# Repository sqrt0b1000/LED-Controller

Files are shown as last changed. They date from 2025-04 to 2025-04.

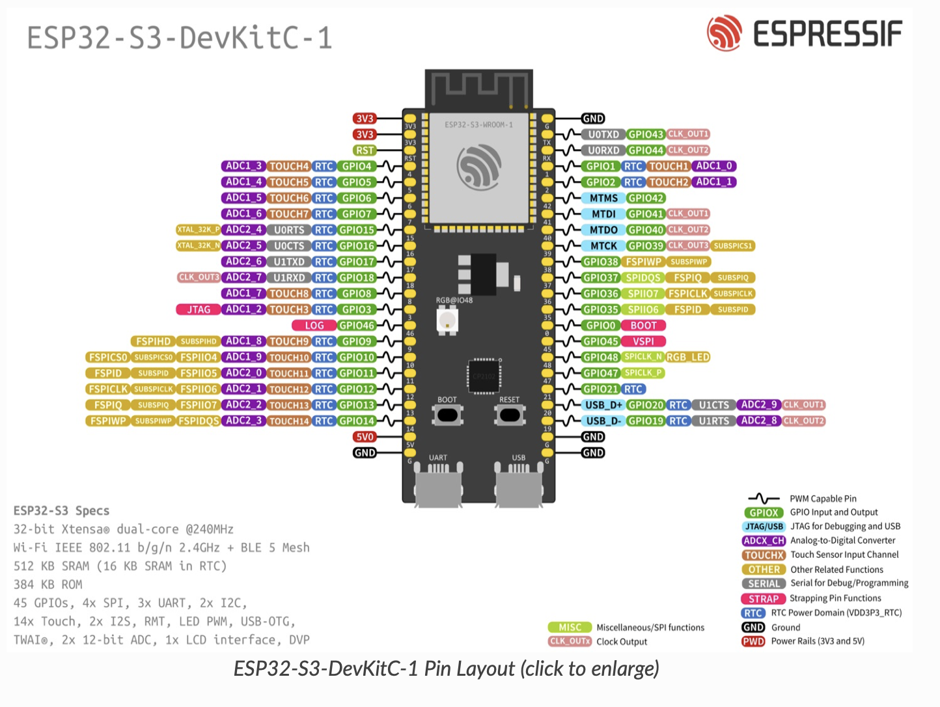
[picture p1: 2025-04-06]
Datasheets/ESP32-S3/Ports-ESP_S3_DevKitC_1.png

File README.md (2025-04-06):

# LED Controller: Schaltplatine für WLED

## Disclaimer

Using this software and hardware is the users responsibility as it is not bug free.
Therefore contributors of this repo are not reliable for anything
including but not limited to spontaneous combustion of the entire led strip, the house and the inevitable heat death of the universe.

Also see: [LICENSE](./LICENSE)

## Features

- 3 PWM Ausgänge zum Steuern von 12 V RGB Kanälen
- Steuerung durch WIFI (einwahl in WLAN möglich oder Erstellen eines eigenen Accesspoints)
- 6 weitere GPIO Pins, z.B. für weitere Buttons,…
- RX/TX Verbindungen (Flashen des ESP32)

## Zusätzliche Features

- 8 PWM Ausgänge als Datenleitungen für individuell addressierbare LEDs
  - Signal auf 5 V
  - Mögliche LED - Strips (nicht vollständig)
    - WS2812
    - WS2805

## Pins

| ESP Pin Name | Board Output | Usage |
| ---:| ---:| ---:|
| TXD0 | J  7 | GPIO1, U0TXD, CLK_OUT3, EMAC_RXD2 |
| RXD0 | J  8 | GPIO3, U0RXD, CLK_OUT2 |
| IO 18 | LED-Out | MOSFET Transisotr 12 V |
| IO 19 | LED-Out | MOSFET Transisotr 12 V |
| IO 21 | LED-Out | MOSFET Transisotr 12 V |
| IO  2 | J  5 | MOSFET Transistor  5 V |
| IO 15 | J 11 | MOSFET Transistor  5 V |
| IO 13 | J 12 | MOSFET Transistor  5 V |
| IO 12 | J 13 | MOSFET Transistor  5 V |
| IO 14 | J 14 | MOSFET Transistor  5 V |
| IO 27 | J 15 | MOSFET Transistor  5 V |
| IO 26 | J 16 | MOSFET Transistor  5 V |
| IO 25 | J 17 | MOSFET Transistor  5 V |
| SENSOR_VN | J 4 | GPIO39, ADC1_CH3, RTC_GPIO3 |
| SENSOR_VP | J 5 | GPIO36, ADC1_CH0, RTC_GPIO0 |
| - | J  9 | Ground |
|  - | J 10 | Power 3.3 V |
|  - | J  2| Power  12 V |

Für mehr Details siehe das Datasheet des Controllers: [Datasheet](./Datasheets/ESP32/esp32-wroom-32_datasheet_en.pdf))

## Probleme mit v01

- sehr hohe Last auf Ground
  - diese Leiterbahnen sollten breiter und idealerweise kürzer sein
- zentraler Ground von ESP32 nicht wirklich lötbar
  - hier richtige Löcher, damit man auf der Rückseite mit dem Lötkolben auch hinkommt
- Pads von Spanungsregulierer anpassen
  - verhindern von Verbindungen von 12 V und 3.3 V beim Löten
- anpassen der Löchergrößen um Pins einfacher durchsteckbar zu machen
- fehlender Pin für 5 V
- Verbindung von Dir mit 5 V, damit Richtung stimmt
- mehr Pins für GND and 12 V
- weitere Pins für freie IO Ports
- Benennung und Beschriftung der Pins
- verbinde benutzbare Pins, nicht (nicht 17-22, da diese intern vom ESP32 benutzt werden, und nicht verbunden sind)

## Flashen des ESP32

(Nur für einen neuen Controller notwendig, alle weiteren Updates können OTA erfolgen)

Verbinden von RX/TX mit Flipper, oder anderem Board.
Flipper oder alternatives Board als UART-USB-Bridge verwenden.
In WLED folgenden Command ausführen.
Davor den Boot-Button am Controller drücken,
um diesen in den Boot-Modus zu versetzen.

´´´bash
pio run -e esp32dev -t upload
´´´
Nach erfolgreichem Flashen den ESP32 mit dem Reset-Button resetten.

## Links

### WLED

- [WLED-Knowlege base](https://kno.wled.ge)
- [WLED-Github](https://github.com/WLED/WLED)
- [WLED-MM](https://github.com/MoonModules/WLED-MM): More advanced WLED with additional / experimental features

### LED-FX (Audio-Reactive)

- [LED-FX-Github](https://github.com/LedFx/LedFx)
- [LED-FX-Documentation](https://docs.ledfx.app/en/latest/installing.html)

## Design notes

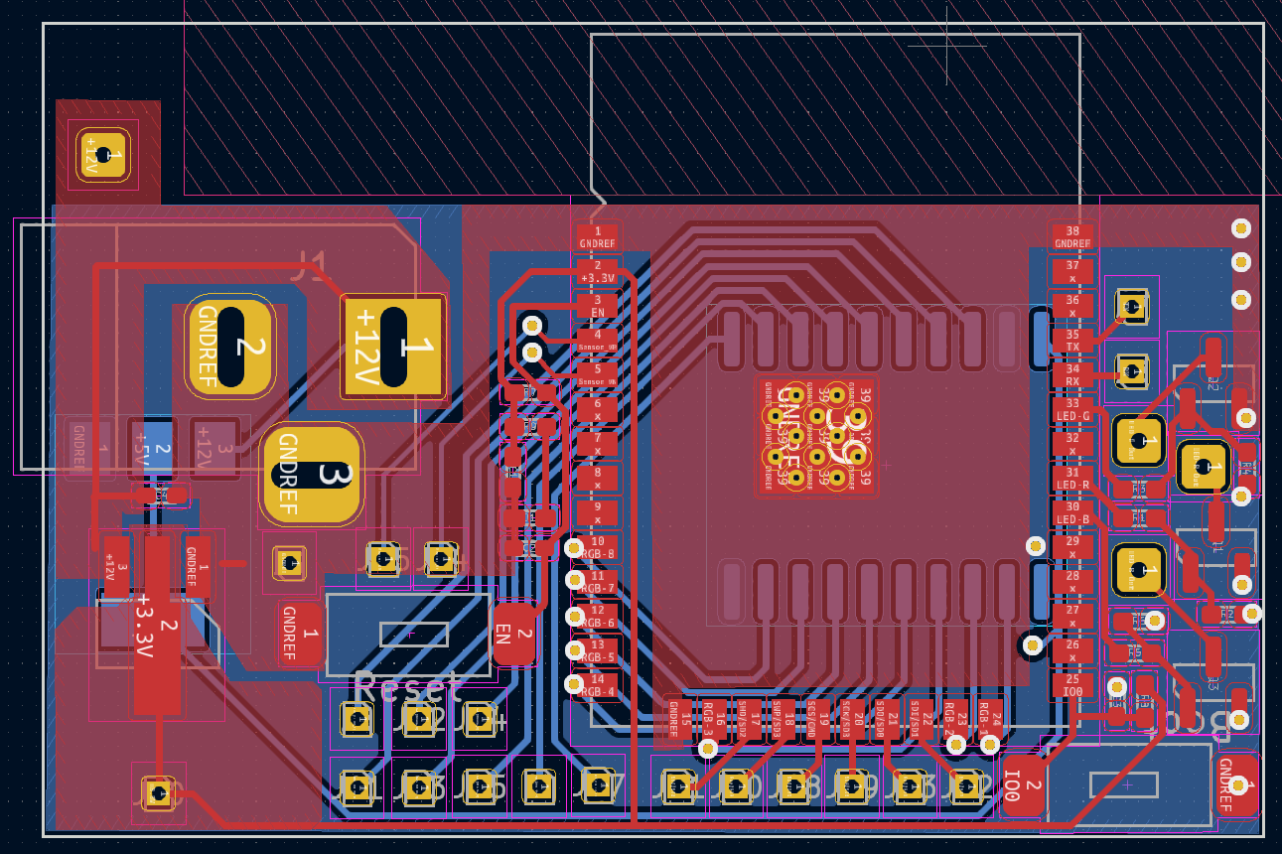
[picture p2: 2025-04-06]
Exports/PCP-Pins.png

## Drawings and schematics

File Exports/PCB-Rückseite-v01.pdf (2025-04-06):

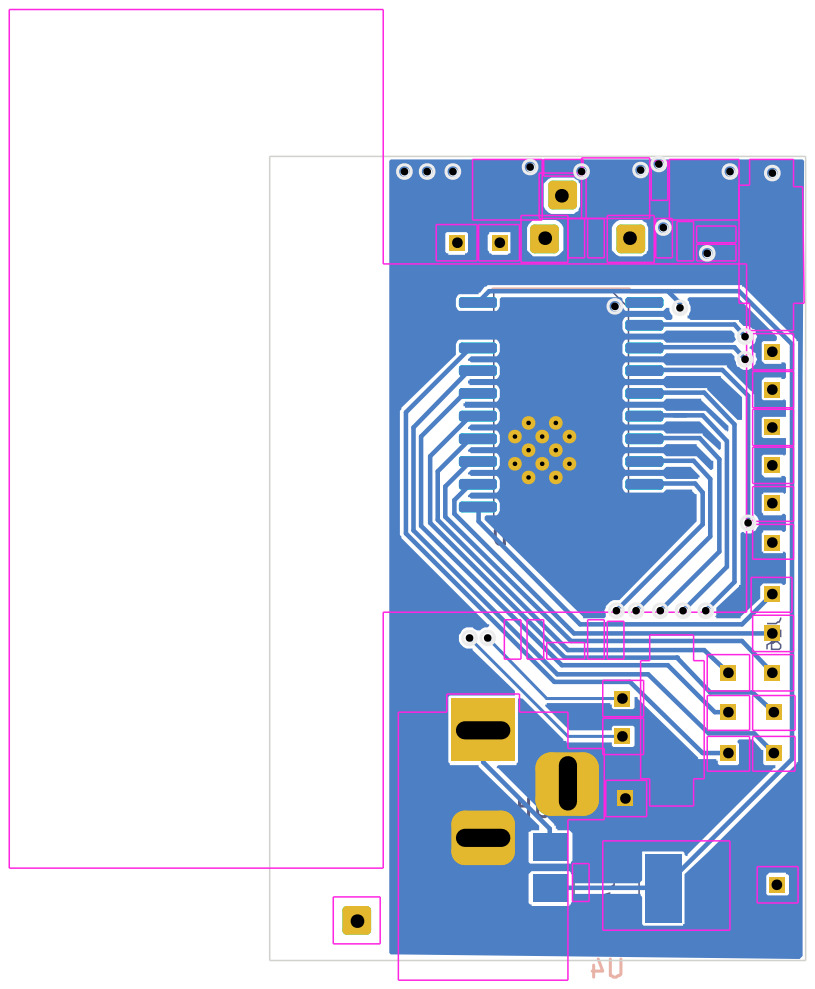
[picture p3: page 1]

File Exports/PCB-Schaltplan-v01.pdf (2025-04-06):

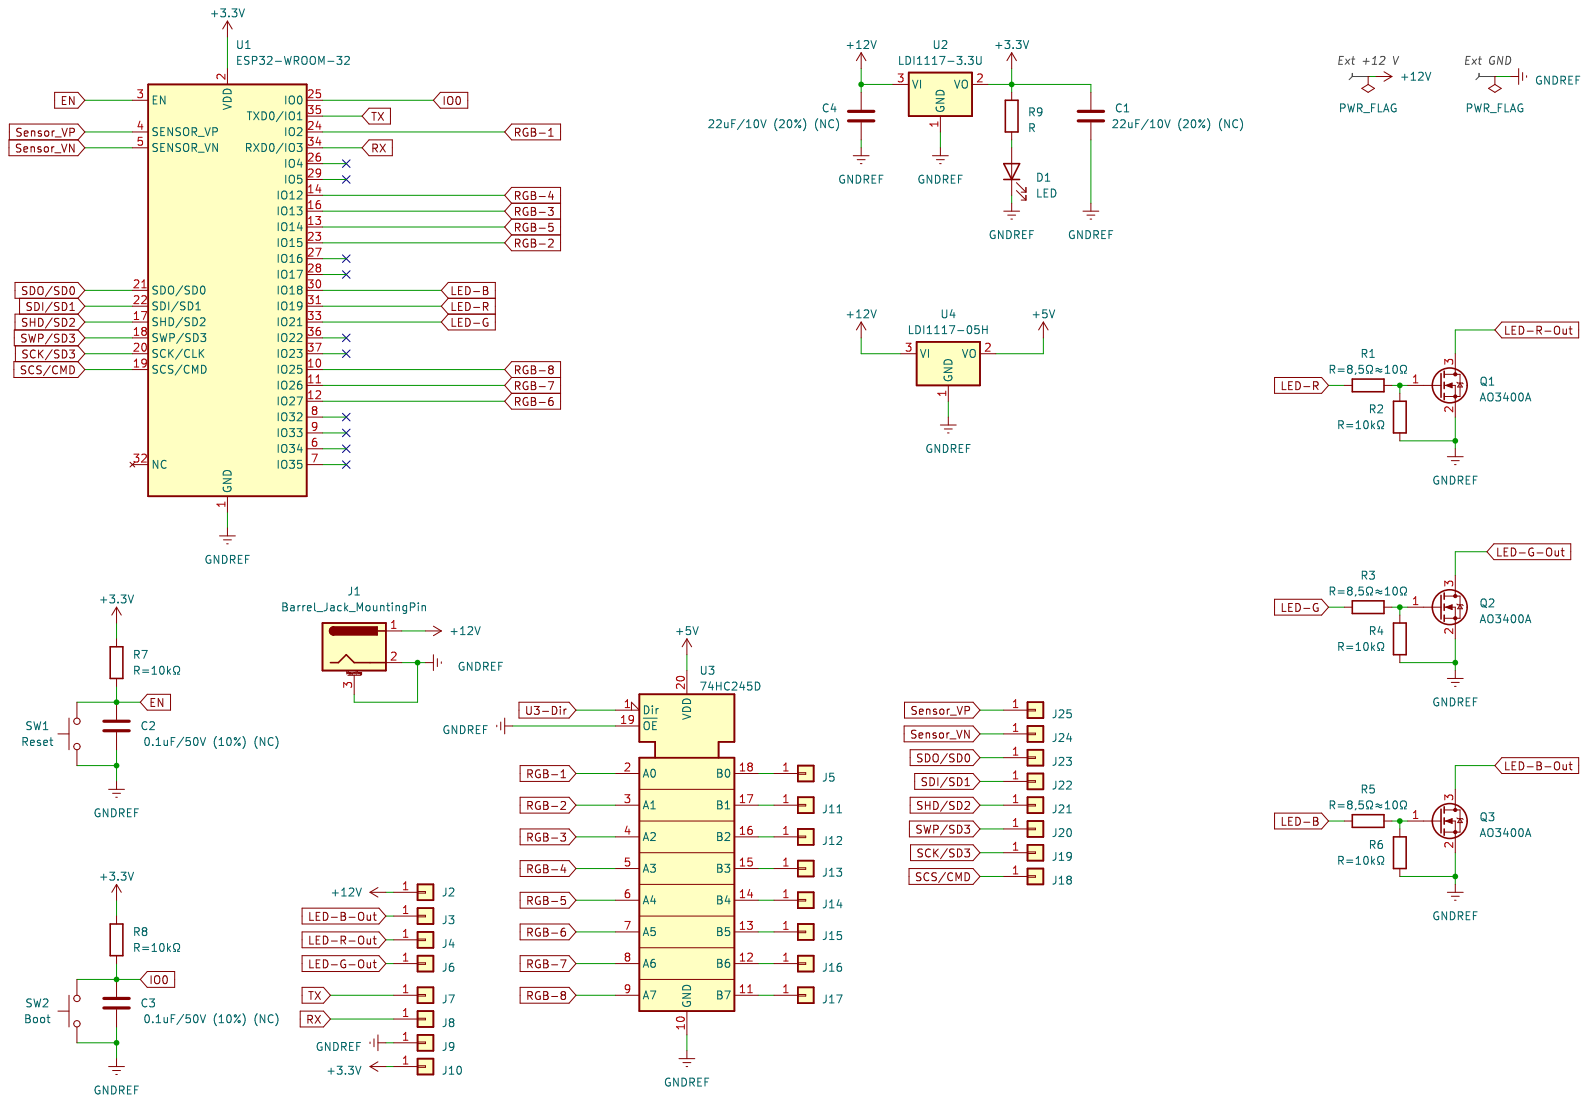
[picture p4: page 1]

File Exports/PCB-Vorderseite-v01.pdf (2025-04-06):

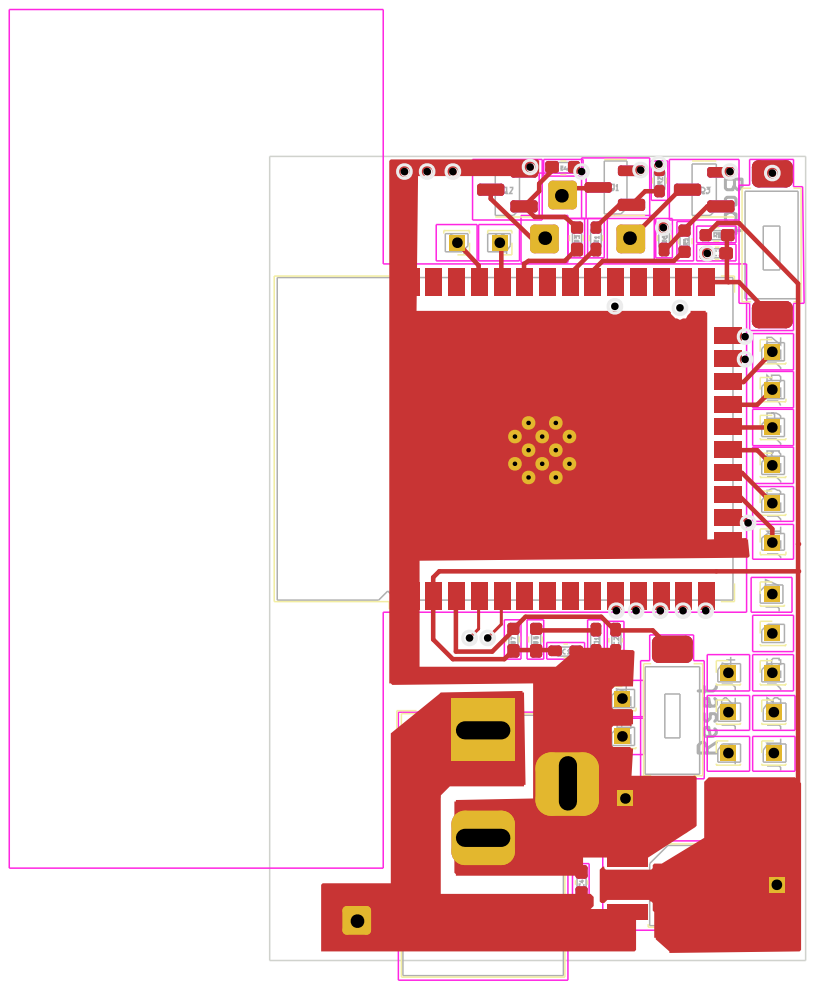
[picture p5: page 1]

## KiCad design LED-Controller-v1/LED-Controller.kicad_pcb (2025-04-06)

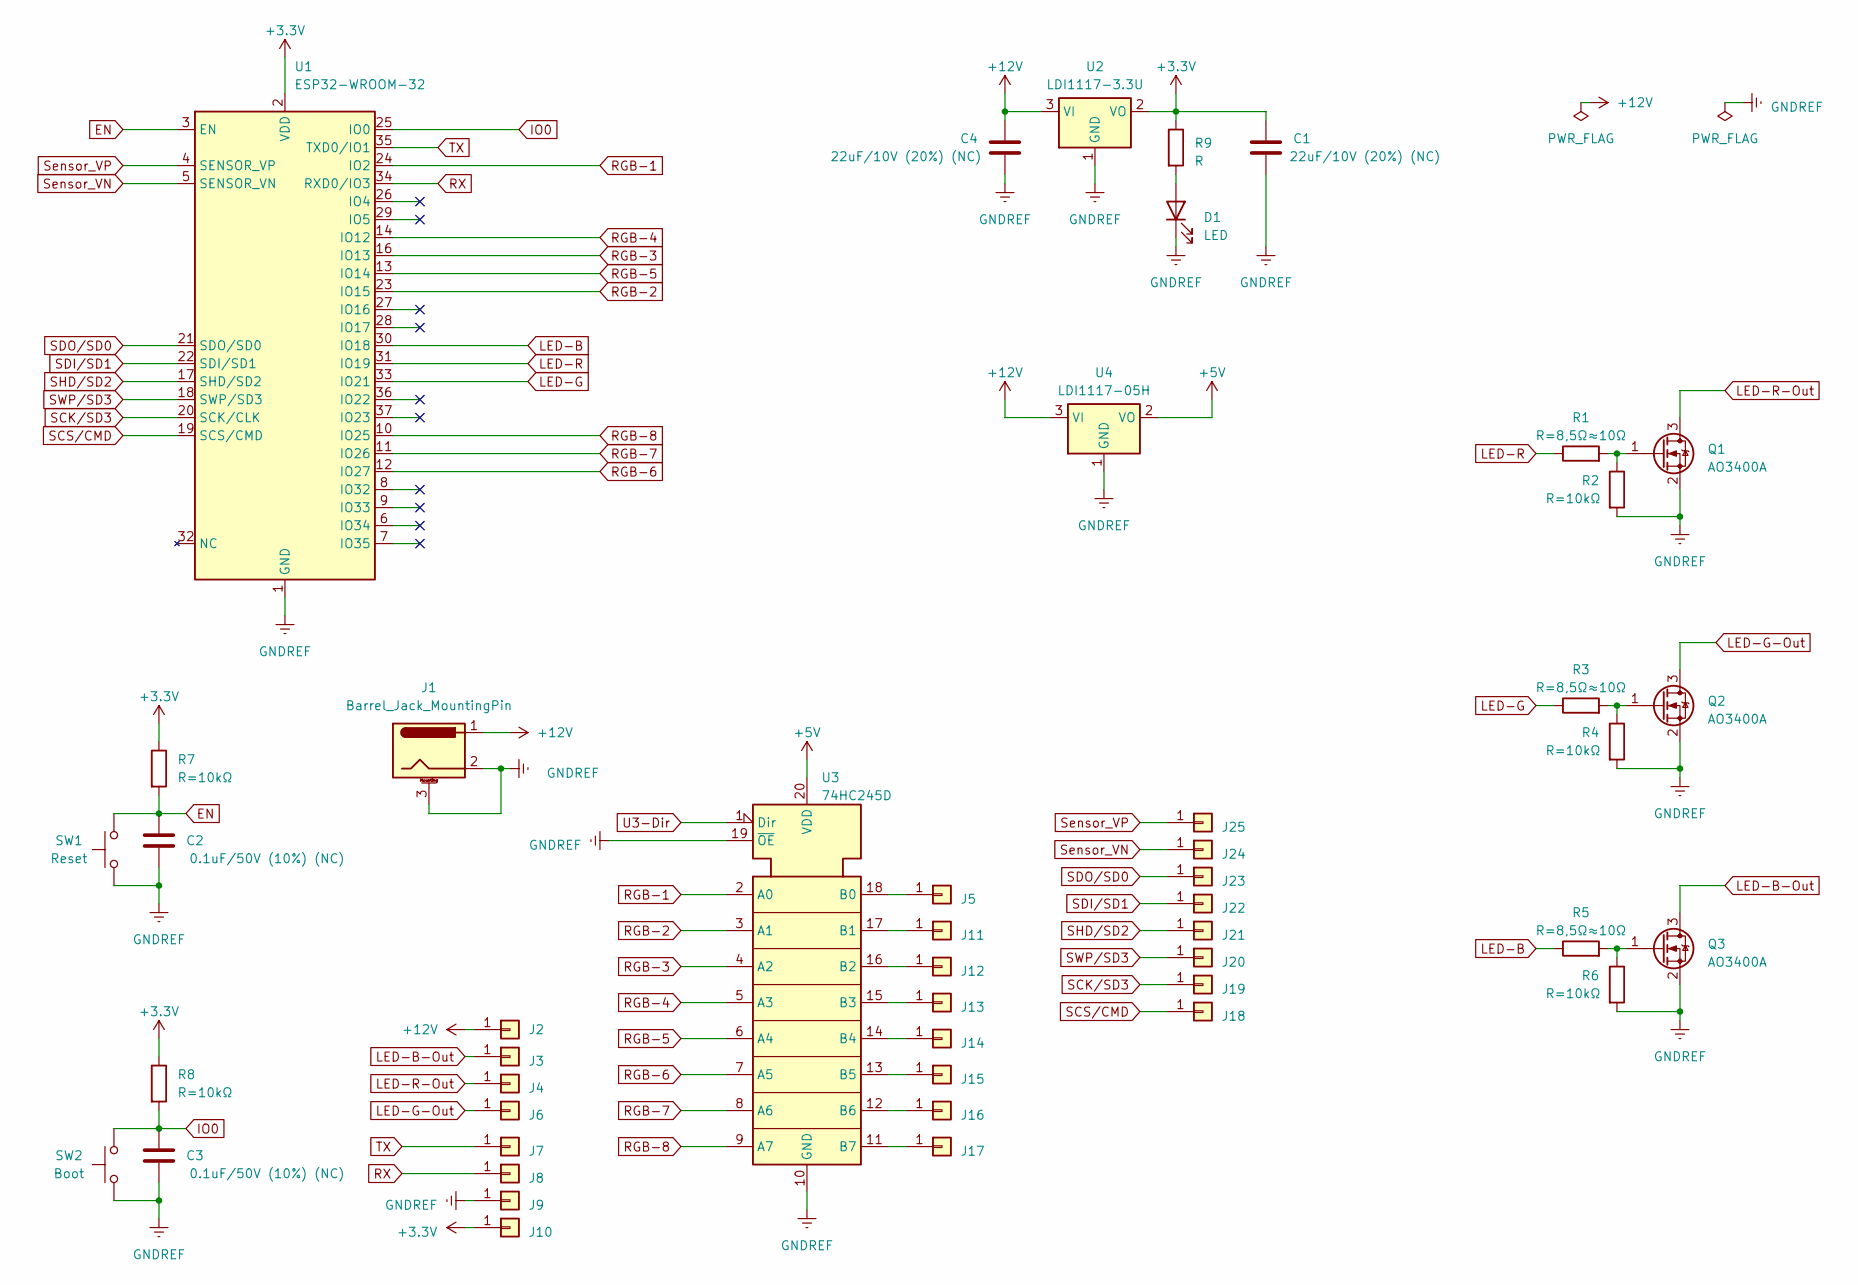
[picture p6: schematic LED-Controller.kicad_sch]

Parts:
C1, C4: 22uF/10V (20%) (NC); C_0402_1005Metric_Pad0.74x0.62mm_HandSolder
C2, C3: 0.1uF/50V (10%) (NC); C_0402_1005Metric_Pad0.74x0.62mm_HandSolder
D1: LED; D_0402_1005Metric_Pad0.77x0.64mm_HandSolder
J1: Barrel_Jack_MountingPin; BarrelJack_Horizontal
J2, J3, J4, J6: Conn_01x01; SolderWire-0.1sqmm_1x01_D0.4mm_OD1mm
J5, J7, J8, J9, J10, J11, J12, J13, J14, J15, J16, J17, J18, J19, J20, J21, J22, J23, J24, J25: Conn_01x01; PinHeader_1x01_P1.00mm_Vertical
Q1, Q2, Q3: AO3400A; SOT-23
R1, R3, R5: R=8,5Ω≈10Ω; R_0402_1005Metric_Pad0.72x0.64mm_HandSolder
R2, R4, R6, R7, R8: R=10kΩ; R_0402_1005Metric_Pad0.72x0.64mm_HandSolder
R9: R; R_0402_1005Metric_Pad0.72x0.64mm_HandSolder
SW1: Reset; TACTM-34N-F
SW2: Boot; TACTM-34N-F
U1: ESP32-WROOM-32
U2: LDI1117-3.3U; SOT-89-3_Handsoldering
U3: 74HC245D; SOIC-20W_7.5x12.8mm_P1.27mm
U4: LDI1117-05H; SOT-223-3_TabPin2

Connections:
+3.3V: C1.2, J10.1, R7.1, R8.1, R9.1, U1.2 (VDD), U2.2 (VO)
+5V: U3.20 (VDD), U4.2 (VO)
+12V: C4.2, J1.1, J2.1, U2.3 (VI), U4.3 (VI)
EN: C2.2, R7.2, SW1.2, U1.3 (EN)
GNDREF: C1.1, C2.1, C3.1, C4.1, D1.1 (K), J1.2, J1.3 (MountPin), J9.1, Q1.2 (S), Q2.2 (S), Q3.2 (S), R2.2, R4.2, R6.2, SW1.1, SW2.1, U1.1 (GND), U1.15 (GND), U1.38 (GND), U1.39 (GND), U2.1 (GND), U3.10 (GND), U3.19 (~OE), U4.1 (GND)
IO0: C3.2, R8.2, SW2.2, U1.25 (IO0)
LED-B: R5.1, U1.30 (IO18)
LED-B-Out: J3.1, Q3.3 (D)
LED-G: R3.1, U1.33 (IO21)
LED-G-Out: J6.1, Q2.3 (D)
LED-R: R1.1, U1.31 (IO19)
LED-R-Out: J4.1, Q1.3 (D)
unnamed: D1.2 (A), R9.2
unnamed: J5.1, U3.18 (B0)
unnamed: J11.1, U3.17 (B1)
unnamed: J12.1, U3.16 (B2)
unnamed: J13.1, U3.15 (B3)
unnamed: J14.1, U3.14 (B4)
unnamed: J15.1, U3.13 (B5)
unnamed: J16.1, U3.12 (B6)
unnamed: J17.1, U3.11 (B7)
unnamed: Q1.1 (G), R1.2, R2.1
unnamed: Q2.1 (G), R3.2, R4.1
unnamed: Q3.1 (G), R5.2, R6.1
RGB-1: U1.24 (IO2), U3.2 (A0)
RGB-2: U1.23 (IO15), U3.3 (A1)
RGB-3: U1.16 (IO13), U3.4 (A2)
RGB-4: U1.14 (IO12), U3.5 (A3)
RGB-5: U1.13 (IO14), U3.6 (A4)
RGB-6: U1.12 (IO27), U3.7 (A5)
RGB-7: U1.11 (IO26), U3.8 (A6)
RGB-8: U1.10 (IO25), U3.9 (A7)
RX: J8.1, U1.34 (RXD0/IO3)
SCK/SD3: J19.1, U1.20 (SCK/CLK)
SCS/CMD: J18.1, U1.19 (SCS/CMD)
SDI/SD1: J22.1, U1.22 (SDI/SD1)
SDO/SD0: J23.1, U1.21 (SDO/SD0)
SHD/SD2: J21.1, U1.17 (SHD/SD2)
SWP/SD3: J20.1, U1.18 (SWP/SD3)
Sensor_VN: J24.1, U1.5 (SENSOR_VN)
Sensor_VP: J25.1, U1.4 (SENSOR_VP)
TX: J7.1, U1.35 (TXD0/IO1)
U3-Dir: U3.1 (Dir)

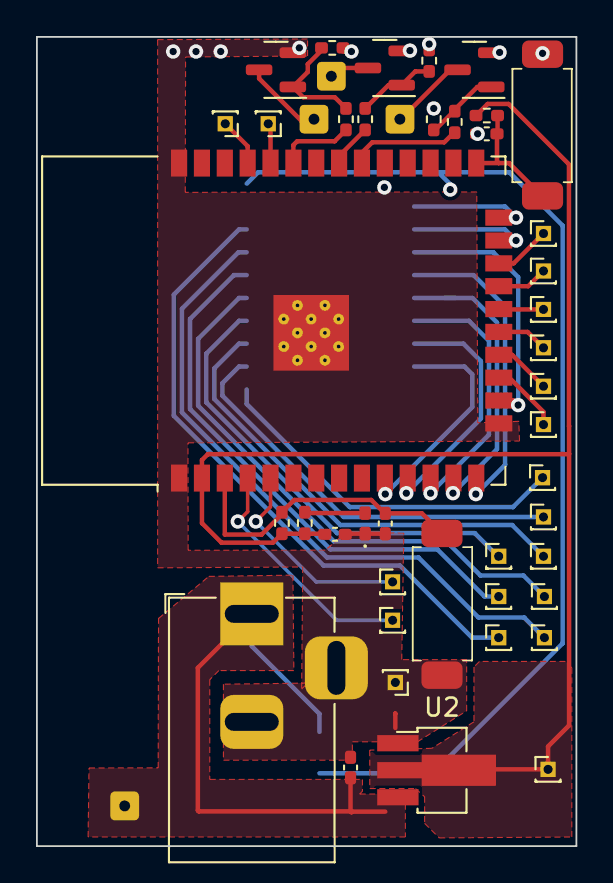
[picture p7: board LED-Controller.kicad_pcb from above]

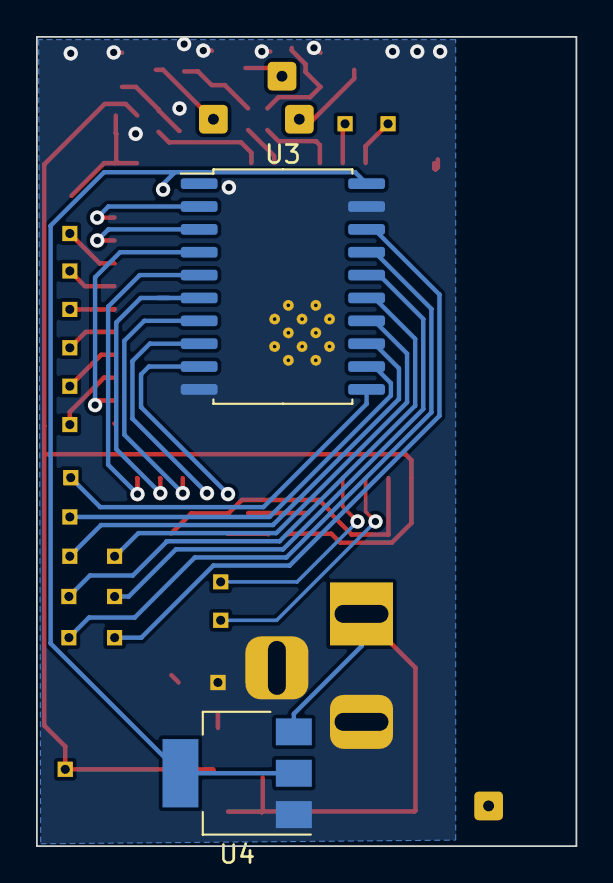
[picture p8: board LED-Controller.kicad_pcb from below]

Board: 2 copper layers, 30.0 x 45.0 mm, 48 parts (2 on the bottom side), 42 nets.
